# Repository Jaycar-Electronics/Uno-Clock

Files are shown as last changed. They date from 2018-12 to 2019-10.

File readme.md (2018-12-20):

## LCD Arduino Clock

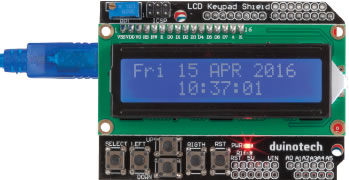
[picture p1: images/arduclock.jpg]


This is an easy project to assemble- just one main board and  two shields, but gives a fully functional, easy to read clock display which  retains the time, even when disconnected from power. You could leave it on your  desk plugged into a USB port on your computer, so that it powers up whenever  the computer is on.

## Components

|Qty| Code | Description |
|---|---|---|
|1 | [XC4410](http://jaycar.com.au/p/XC4410) | uno main board
|1 | [XC4536](http://jaycar.com.au/p/XC4536) | datalogging shield
|1 | [XC4454](http://jaycar.com.au/p/XC4454) | LCD shield

## Connections

All the connections are made with interconnects on the  shield, but the following are the important pins:

|Pin | Function
| --- | ---
| A4(SDA) |12C Data
|A5(SCL) |12C Clock
|D10 |SD Card Select
|D11 |Master In Slave Out
|D12 |Master Out Slave In
|D13 |Serial Clock
|A0 | Pushbuttons
|D4 | LCD Data bit0 (in 4bit mode)
|D5 | LCD Data bit1 (in 4bit mode)
|D6 | LCD Data bit2 (in 4bit mode)
|D7 | LCD Data bit3 (in 4bit mode)
|D8 | LCD Register select
|D9 | LCD Enable

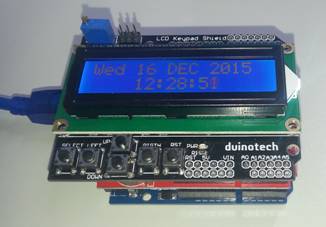
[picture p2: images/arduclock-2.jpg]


Stack the shields, first the Data Log Shield onto the Uno,  then the LCD Shield onto the Data Log Shield. Make sure you’ve got the RTClib  Library installed. The project also uses the Wire and LCD libraries, but they  are included with the Arduino IDE.

Compile and upload the code to the board, and the clock  should display a time and date (which probably isn’t right). The clock can be  adjusted by pressing select, then left and right to choose which field to edit,  and up and down to adjust the field. The seconds can only be set to zero rather  than adjusted up or down. Press select again to return to clock mode.

## Improvements

With the addition of a buzzer module, the code could be  modified to act as an alarm clock. Once the clock is set, the sketch on the  main board can be changed, so the buttons could be reprogrammed to operate  different functions, such as a countdown timer.

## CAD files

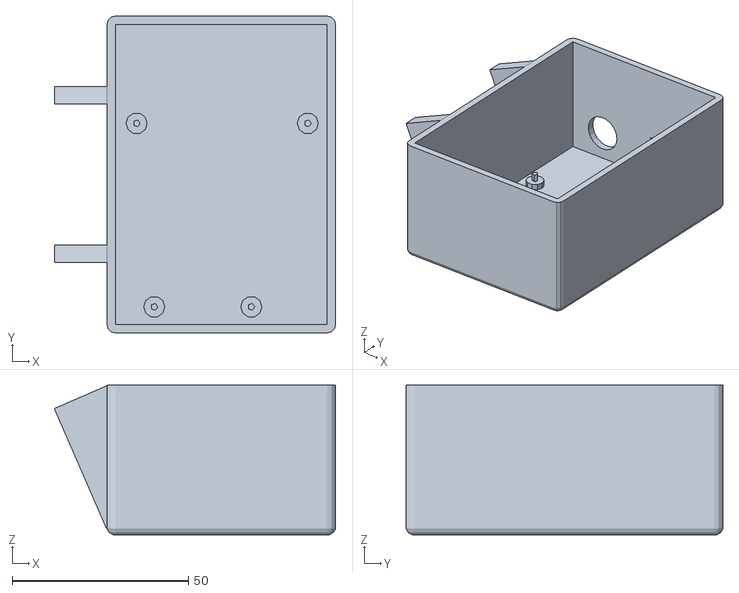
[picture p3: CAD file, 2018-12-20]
3d case files/ArduinoClockLegs3.stl
79.7 x 89.8 x 42.4

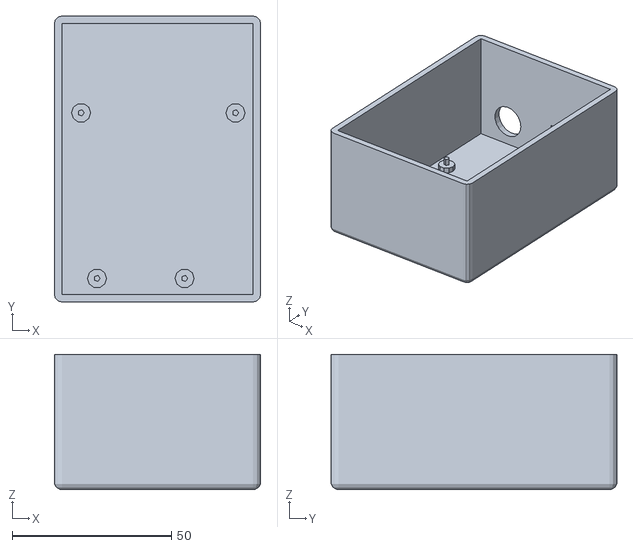
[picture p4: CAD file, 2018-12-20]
3d case files/ArduinoClock3.stl
64.8 x 89.8 x 42.5

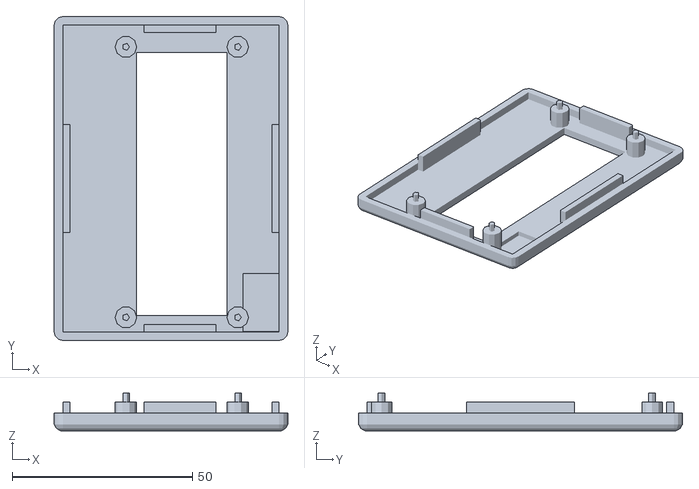
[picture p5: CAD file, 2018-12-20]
3d case files/ArduinoClockLid3.stl
64.8 x 89.8 x 10.4

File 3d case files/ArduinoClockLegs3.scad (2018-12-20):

module cbox(x,y,z,c){       //curved box template
    minkowski(){
cube([x-2*c,y-2*c,z-2*c]);
    translate([c,c,c])
    sphere(r=c,$fn=12);
}
}

module pillar(){                //standoff pillar template
translate([0,0,0.5])
    cylinder(r=3,h=4);
    translate([0,0,1])
    cylinder(r=1,h=6);
}

difference(){                   //hollow box
union(){
    
cbox(65,90,50,2.5);             //main body

rotate([0,-23.5,0])
translate([0.7,20,1.8])
cube([30,5,37]);             //legs (so they get carved away right)

rotate([0,-23.5,0])
translate([0.7,65,1.8])
cube([30,5,37]);             //legs (so they get carved away right)
}
translate([2.5,2.5,2.5])            //hollow interior
    cube([60,85,50]);

translate([-5,-5,42.5])             //flat top
    cube([120,120,100]);

translate([35,80,4.5])      //square cutout for USB
  cube([15,20,13]);
//translate([42.5,80,11])     //round cutout for USB
  //  rotate([270,0,0])
    //cylinder(r=8,h=20);

translate([15,80,12])     //round cutout for dc jack
    rotate([270,0,0])
    cylinder(r=6,h=20);

}

translate([13.5,7.5,0])           //pillars
pillar();
translate([41,7.5,0])
pillar();
translate([8.5,59.5,0])
pillar();
translate([57,59.5,0])
pillar();

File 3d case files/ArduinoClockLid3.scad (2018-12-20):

module cbox(x,y,z,c){       //curved box template
    minkowski(){
cube([x-2*c,y-2*c,z-2*c]);
    translate([c,c,c])
    sphere(r=c,$fn=12);
}
}

module pillar(){                //standoff pillar template
translate([0,0,-3])
    cylinder(r=3,h=7.5);
    translate([0,0,1]);
    cylinder(r=1,h=7);
}


difference(){                   //hollow box
cbox(65,90,50,2.5);
translate([2.5,2.5,2.5])            //hollow interior
    cube([60,85,50]);

translate([-5,-5,5])             //flat top
    cube([120,120,100]);

translate([52.4,2.6,1])
    cube([10,16,10]);            //notch for pot
    
translate([23,7,-1])
    cube([25,73,10]);            //cutout for display
    


}

translate([20,6.5,3.5])           //pillars
pillar();
translate([51,6.5,3.5])
pillar();
translate([20,81.5,3.5])
pillar();
translate([51,81.5,3.5])
pillar();

translate([2.5,30,1])           //catch for body
    cube([2,30,7]);

translate([60.5,30,1])           //catch for body
    cube([2,30,7]);

translate([25,2.5,1])           //catch for body
    cube([20,2,7]);

translate([25,85.5,1])           //catch for body
    cube([20,2,7]);

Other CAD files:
3d case files/ArduinoClock3.scad

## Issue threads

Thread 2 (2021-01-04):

Issues with reseting - with possible solution

chrisco484, 2021-01-04:
I had an issue with two Arduino Uno boards (clones) where everything works fine after a power up but when I hit the reset button the screen was occasionally garbled.

What I found fixed it was not to create the LiquidCrystal object in global space but create it with 'new' in the setup.

I'm not 100% sure but this is my theory:

The LiquidCrystal constructors calls init which always calls begin() . begin() immediately performs the initialization of the display.

Objects instantiated at global scope are created immediately at program start up and so the LCD initialization is occurring virtually instantly.

However, by creating the LiquidCrystal object in setup() we can introduce a delay to make sure that all the reset circuitry has had a chance to settle down. I haven't had one reset failure since changing my sketches to initialize in this way.

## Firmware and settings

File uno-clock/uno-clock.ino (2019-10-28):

// Date and time functions using a DS1307 RTC connected via I2C and Wire lib

#include <Wire.h>
#include "RTClib.h"
#include <LiquidCrystal.h>

//pin for buttons
#define KEYPIN A0
//button constants
#define btnRIGHT 6
#define btnUP 5
#define btnDOWN 4
#define btnLEFT 3
#define btnSELECT 2
#define btnNONE (-1)

RTC_DS1307 rtc;
LiquidCrystal lcd(8, 9, 4, 5, 6, 7); //LiquidCrystal lcd(RS, E, b4, b5, b6, b7);

char daysOfTheWeek[7][12] = {"Sunday", "Monday", "Tuesday", "Wednesday", "Thursday", "Friday", "Saturday"};
char monthsOfTheYear[12][4] = {"JAN", "FEB", "MAR", "APR", "MAY", "JUN", "JUL", "AUG", "SEP", "OCT", "NOV", "DEC"};
char dOfTheWeek[7][4] = {"Sun", "Mon", "Tue", "Wed", "Thu", "Fri", "Sat"};
char setphase = 0;                      //to know whether we are setting the clock or not
char setpos = 0;                        //setting y/m/d/h/m/s
char cursorx[6] = {5, 7, 14, 5, 8, 11}; //where to place cursor in set mode
char cursory[6] = {0, 0, 0, 1, 1, 1};

DateTime now; //set as global so we can update between loops

void setup()
{
  Serial.begin(9600);
  lcd.begin(16, 2);
  lcd.clear();
  if (!rtc.begin())
  {
    Serial.println("Couldn't find RTC");
    while (1)
      ;
  }
}

void loop()
{
  if (!setphase)
  {
    now = rtc.now();
  } //only update clock if we're not in setting mode

  dobuttons(); //respond to button presses

  Serial.print(now.year(), DEC);
  Serial.print('/');
  Serial.print(now.month(), DEC);
  Serial.print('/');
  Serial.print(now.day(), DEC);
  Serial.print(" (");
  Serial.print(dOfTheWeek[now.dayOfTheWeek()]);
  Serial.print(") ");
  Serial.print(now.hour(), DEC);
  Serial.print(':');
  Serial.print(now.minute(), DEC);
  Serial.print(':');
  Serial.print(now.second(), DEC);
  Serial.println();

  lcd.setCursor(0, 0);
  lcd.print(dOfTheWeek[now.dayOfTheWeek()]);
  lcd.print(" ");
  lcd.print(tens(now.day()), DEC);
  lcd.print(units(now.day()), DEC);
  lcd.print(' ');
  lcd.print(monthsOfTheYear[now.month() - 1]);
  lcd.print(' ');
  lcd.print(now.year(), DEC);
  lcd.print(' ');

  lcd.setCursor(4, 1);
  lcd.print(tens(now.hour()), DEC);
  lcd.print(units(now.hour()), DEC);
  lcd.print(':');
  lcd.print(tens(now.minute()), DEC);
  lcd.print(units(now.minute()), DEC);
  lcd.print(':');
  lcd.print(tens(now.second()), DEC);
  lcd.print(units(now.second()), DEC);
  lcd.print(' ');
  lcd.setCursor(cursorx[setpos], cursory[setpos]); //place flashing cursor in set mode
  delay(150);                                      //short enough to pick up brief keypresses
}

char tens(int n) { return (n / 10) % 10; } //to help show leading zeroes

char units(int n) { return n % 10; } //to help show leading zeros

int read_LCD_buttons()
{
  int adc_key_in = 0;
  adc_key_in = analogRead(KEYPIN);           // read the value from the sensor
  delay(5);                                  //switch debounce delay. Increase this delay if incorrect switch selections are returned.
  int k = (analogRead(KEYPIN) - adc_key_in); //gives the button a slight range to allow for a little contact resistance noise
  if (5 < abs(k))
    return btnNONE; // double checks the keypress. If the two readings are not equal +/-k value after debounce delay, it tries again.
  // my buttons when read are centered at these valies: 0, 144, 329, 504, 741
  // we add approx 50 to those values and check to see if we are close
  if (adc_key_in > 1000)
    return btnNONE; // We make this the 1st option for speed reasons since it will be the most likely result
  if (adc_key_in < 50)
    return btnRIGHT;
  if (adc_key_in < 195)
    return btnUP;
  if (adc_key_in < 380)
    return btnDOWN;
  if (adc_key_in < 555)
    return btnLEFT;
  if (adc_key_in < 790)
    return btnSELECT;
  return btnNONE; // when all others fail, return this...
}

void dobuttons()
{
  int key;
  key = read_LCD_buttons();
  if (key == btnSELECT)
  {
    if (setphase == 0)
    {
      setphase = 1;
      lcd.blink();
      setpos = 3;
    } //phase 1 is starting set mode, but select key still pressed, turn cursor on, default to changing hour
    if (setphase == 2)
    {
      setphase = 3;
      lcd.noBlink();
      rtc.adjust(now);
    } //phase 3 is ending set mode, but select key still pressed, turn cursor off, need to update RTC to edited time
  }
  if (key == btnNONE)
  {
    if (setphase == 1)
    {
      setphase = 2;
    } //phase 2 is in set mode select key released
    if (setphase == 3)
    {
      setphase = 0;
    } //phase 0 is normal mode, select key released
  }

  if (setphase == 2)
  { //respond to keys in setting mode
    if (key == btnLEFT)
    {
      setpos = setpos - 1;
      if (setpos < 0)
      {
        setpos = 5;
      }
    }
    if (key == btnRIGHT)
    {
      setpos = setpos + 1;
      if (setpos > 5)
      {
        setpos = 0;
      }
    }

    int syear, smon, sday, shour, smin, ssec;
    syear = now.year();
    smon = now.month();
    sday = now.day();
    shour = now.hour();
    smin = now.minute();
    ssec = now.second();
    if (key == btnUP)
    {
      if (setpos == 0)
      {
        sday = sday + 1;
        if (sday > 31)
        {
          sday = 1;
        }
      }
      if (setpos == 1)
      {
        smon = smon + 1;
        if (smon > 12)
        {
          smon = 1;
        }
      }
      if (setpos == 2)
      {
        syear = syear + 1;
      }
      if (setpos == 3)
      {
        shour = shour + 1;
        if (shour > 23)
        {
          shour = 0;
        }
      }
      if (setpos == 4)
      {
        smin = smin + 1;
        if (smin > 59)
        {
          smin = 0;
        }
      }
      if (setpos == 5)
      {
        ssec = 0;
      }
      rtc.adjust(DateTime(syear, smon, sday, shour, smin, ssec)); //update clock
      now = rtc.now();                                            //reload into now
    }
    if (key == btnDOWN)
    {
      if (setpos == 0)
      {
        sday = sday - 1;
        if (sday < 1)
        {
          sday = 31;
        }
      }
      if (setpos == 1)
      {
        smon = smon - 1;
        if (smon < 1)
        {
          smon = 12;
        }
      }
      if (setpos == 2)
      {
        syear = syear - 1;
      }
      if (setpos == 3)
      {
        shour = shour - 1;
        if (shour < 0)
        {
          shour = 23;
        }
      }
      if (setpos == 4)
      {
        smin = smin - 1;
        if (smin < 0)
        {
          smin = 59;
        }
      }
      if (setpos == 5)
      {
        ssec = 0;
      }
      rtc.adjust(DateTime(syear, smon, sday, shour, smin, ssec)); //update clock
      now = rtc.now();                                            //reload into now
    }
  }
}
